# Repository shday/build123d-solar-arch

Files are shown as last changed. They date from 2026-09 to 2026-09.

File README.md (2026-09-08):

# build123d-solar-arch

Parametric 3D model of a **solar panel support arch**, generated in code with [build123d](https://build123d.readthedocs.io/) (Python CAD on OpenCASCADE). The script builds the complete structure — frames, feet, crossbars, braces, and lifting padeyes — from a handful of parameters, renders it in the ocp-vscode 3D viewer, and exports an STL mesh. It also builds a **crude sailboat stern context model** alongside the arch (front feet on the horizontal deck, back feet on the sloping transom) purely for visualization — the context hull is a separate part and never enters the STL export or the mass estimate.

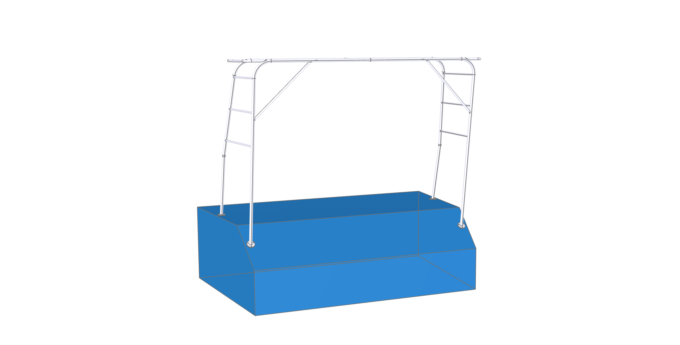
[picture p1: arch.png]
arch


## The model

A 3.1 m wide portal-style frame made of 40 mm round tube (2 mm wall), with:

- **Front and back frames** — filleted corners (R200) with horizontal top rails at 2 m. The **front legs** rise x-plumb (vertical when viewed from ahead) from the deck up to `leg_bend_height` = 0.8 m, then lean inboard toward the top corner; the aft rake is continuous along the whole leg, so the side view is unchanged. The plumb lower run lines the legs up with the boat's existing stern rails
- **Top-plane wings** — U-shaped Ø25 extensions capping both ends of the top bay in the top plane (z = 2 m): the front/back top rails continue ~0.25 m outboard (`wing_extend`) and are joined by a round bar with tight R75 corners, so the wings + arch top form one rounded rectangle ≈ 3.0 m × 0.8 m — extra mounting length for solar panels and clamp points (e.g. a Starlink antenna)
- **ArchFeet** — Ø100 × 8 mm base plates with a Ø30 centre hole and 3× Ø8.5 bolt holes (PCD 75)
- **Top support & center support** — Ø25 crossbars spanning front ↔ back at the top
- **Three side rails** per side — Ø25 panel-mounting rails running between the front and back legs at even heights: one at `side_rail_drop` below the top plane, one `side_rail_bottom_height` (1 m) above the deck, and one halfway between. Each rail is anchored at the same z on both legs, so every rail is level and parallel to the top support whatever rake/tilt the legs have
- **Diagonal brace** — Ø25 bracing in the plane of the back frame
- **Two padeyes** — Ø25 half-torus lifting lugs on the outside of the back top rail
- The half-model is mirrored about mid-span for a symmetric structure

A **crude stern-context hull** is shown beside the arch (translucent, not fused):
a flat deck at z=0 carries the front (flat) feet, while the back (tilted) feet
rest on a sloped transom/scoop surface. The scoop plane is *measured from the
arch's own back feet* (`back_foot_angle`, `drop`), and the hull is carved so
that plane becomes its aft top surface — the arch therefore always sits flush
on the hull. See the `boat_*` / `deck_width_*` parameters.

Current export: `arch.stl`, arch only (~22 MB, ~440k triangles — the STL mesh
density inflated after the plumb knee and wings were added, an OCCT meshing
artefact; geometry is unchanged in volume/fit checks); the context hull is never
included.

## Requirements

- Python 3.13 + conda environment `ocp` (build123d 0.11.1, cadquery-ocp-novtk, ocp-vscode, numpy, …)

Create the environment:

```bash
conda env create -f environment.yaml   # env name: ocp
```

## Running

```bash
cd /path/to/build123d-solar-arch   # run from the project root
conda activate ocp
python solar_arch.py
```

This builds the model, sends it to the 3D viewer (`show(arch2, boat)`), and writes `arch.stl` (`export_stl`) plus `arch.png` (`save_screenshot`, requires the viewer to be open).

> **Headless runs:** pass `--no-viewer` to skip `show()`/`save_screenshot()` while
> still building the geometry, running the fit checks, and exporting `arch.stl`:
> `python solar_arch.py --no-viewer`.

> **Run from the project directory.** `solar_arch.py` is opened relative to your
> current working directory, not the script's location. If you get
> `python: can't open file '.../solar_arch.py': No such file or directory`, you are
> in the wrong folder — `cd` into this repo first (check with `pwd`).

> **No conda on PATH?** Conda isn't initialized in your shell yet. Either run once
> `<conda-prefix>/bin/conda init zsh` (e.g. `/Users/stephenday/miniconda3/bin/conda init zsh`),
> or skip activation and call the env's interpreter directly:
> `<conda-prefix>/envs/ocp/bin/python solar_arch.py`.

## Viewing & screenshots

`show()` needs a running viewer:

- **VSCode** — install the *OpenCascade CAD Viewer* extension (`bernhard-42.ocp-cad-viewer`).

  **Recommended flow:** open `solar_arch.py` as the active tab in VSCode — the
  `from ocp_vscode import *` line auto-launches the viewer (`Ocp CAD Viewer >
  Advanced: Autostart`). Confirm the viewer is up: the VSCode status bar shows
  `OCP: <port>` and `~/.ocpvscode` lists that port under `services`. Then run the
  script from **that VSCode window's integrated terminal**:

  ```bash
  python solar_arch.py
  ```

  If the viewer doesn't auto-start, open it manually via the Command Palette
  (`Cmd+Shift+P`) → **"OCP CAD Viewer: Open viewer"**. If `show()` still reports
  `Port could not be cast to integer value as 'None'`, no viewer is registered —
  ensure the viewer panel is open before running.
- **Standalone (no VSCode)** — start the built-in browser viewer:

  ```bash
  python -m ocp_vscode          # serves http://127.0.0.1:3939/viewer
  ```

  Open that URL, then run `solar_arch.py` — the model appears in the browser.

> **Version pairing:** the `ocp-vscode` Python package and the *OCP CAD Viewer*
> VSCode extension are released in lockstep and must match (currently 4.0.1).
> If `show()` fails with `KeyError` (e.g. `'none'` or `0`) in `config.status()`,
> your Python package and extension versions are out of sync — upgrade the
> Python side with `pip install -U ocp-vscode==<extension version>`.

The script saves `arch.png` automatically at the end of each run (`save_screenshot`), so the preview stays in sync with the model. To capture a different view manually:

```python
from ocp_vscode import save_screenshot
save_screenshot("other.png")    # saved relative to the process working directory
```

Or use the camera/screenshot button in the viewer toolbar.

## Parameters

All dimensions are in **millimetres** (`M` = 1000, `MM` = 1). Edit the constants at the top of `solar_arch.py`:

| Parameter | Default | Description |
|---|---|---|
| `width` | 3.1 m | total span (x direction) |
| `back_width` | 2.9 m | span between the back feet |
| `back_inset` | 0.1 m | `(width − back_width) / 2`, leg inset from the outside |
| `height` | 2.0 m | top rail height |
| `depth` | 1.0 m | front-to-back depth of the frame |
| `drop` | 0.2 m | how far the back feet sit below the deck/scoop crease (transom drop) |
| `back_foot_angle` | 40° | tilt of the back foot plates — sets the transom/scoop slope the hull is built to |
| `front_offset` / `back_offset` | 0.5 / 0.3 m | aft rake of the front / back legs at the top |
| `leg_bend_height` | 0.8 m | height above the deck where the front legs start leaning inboard (they rise x-plumb below this, for stern-rail alignment) |
| `wing_extend` | 0.25 m | how far the top-plane wings extend outboard past the top rail ends |
| `wing_od` | 25 mm | wing tube outer diameter (ID 22 mm at `rail_wall_thickness`) |
| `wing_corner_radius` | 75 mm | tight radius of the wings' U corners (vs the arch's R200) |
| `tube_od` / `wall_thickness` | 40 / 2 mm | frame tube outer diameter and wall thickness (ID 36 mm) |
| `rail_wall_thickness` | 1.5 mm | wall of the Ø25 secondary members (cross members, side supports, wings) |
| `cross_member_od` | 25 mm | cross-member (top support, side rails, brace, center support) outer diameter (ID 22 mm at `rail_wall_thickness`) |
| `bend_radius` | 200 mm | corner fillet radius (`5 × tube_od`) |
| `top_support_offset` | 0.25 m | top crossbar position along the top rails |
| `side_rail_drop` | 0.2 m | how far below the top plane the top side rail sits (all rails are anchored at equal heights on both legs, so each is level by construction) |
| `side_rail_bottom_height` | 1.0 m | height of the lowest side rail above the deck (the middle rail sits halfway between this and the top rail) |
| `brace_offset` | 0.5 m | diagonal brace position along the back legs |
| `rise_rate` | 0 | experimental crown rise (`TangentArc`); `0` = flat top |
| `show_boat` | True | build & show the crude stern-context hull beside the arch |
| `boat_cx` | 1.55 m | boat centreline x (`width/2`); hull symmetric about it |
| `deck_width_aft` | 3.0 m | hull width at the aft end (`hull_aft_end`) |
| `deck_width_fwd` | 3.4 m | hull width at the forward cut |
| `hull_aft_end` | 1.3 m | hull aft extent below the scoop surface |
| `hull_len_aft` | 1.5 m | modeled hull length forward of the transom crease |
| `hull_bottom_z` | −1.0 m | flat-bottom depth |

## Project layout

```
solar_arch.py      parametric model (single script)
arch.stl           exported STL mesh
environment.yaml   conda environment (Python 3.13)
arch.png           rendered preview
LICENSE            Apache License 2.0
```

## Known issues

- **build123d 0.11.1 mirror bug:** the generic `mirror()` operation deep-copies the
  part internally, and on this geometry the copy corrupts trimmed-curve parameters
  (OCCT `Geom_TrimmedCurve::parameters out of range`). The script therefore mirrors
  via `arch2.part.mirror(plane)` (no copy) and `add()`s the result — keep that
  pattern for any new mirroring.
- `rise_rate` and the `TangentArc` branch are experimental; `back_foot_angle` and the
  `faces().sort_by(Axis.Z)[-4]` foot split index are empirical values.

## License

Apache License 2.0 — see [LICENSE](LICENSE).

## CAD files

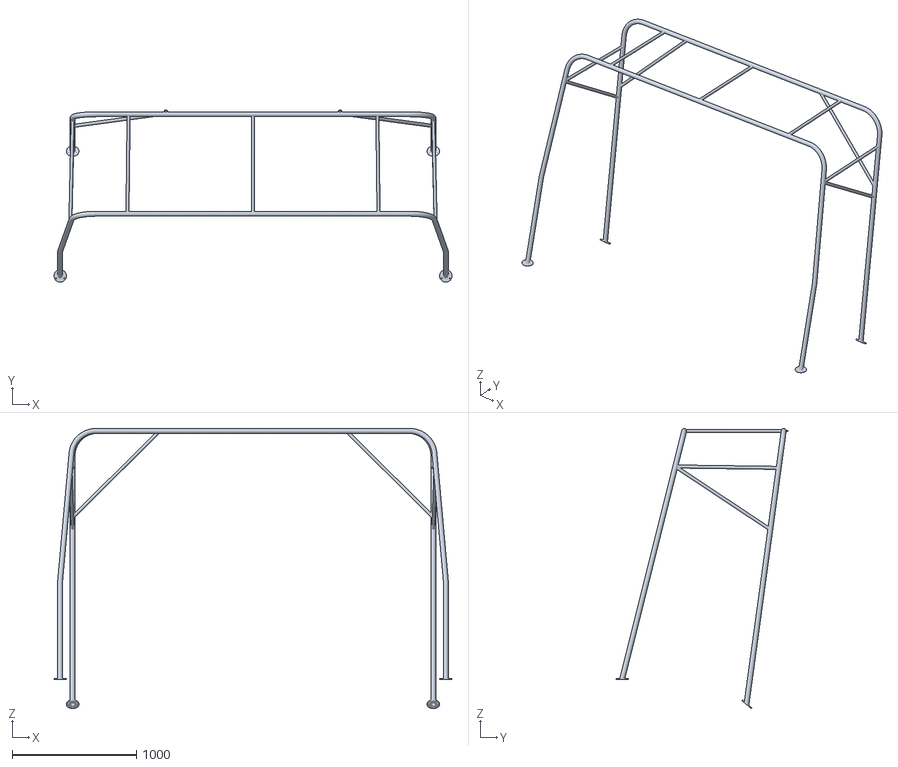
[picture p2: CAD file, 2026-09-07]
arch.stl
3200.0 x 1385.5 x 2252.1

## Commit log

2025-09-11 added stl export
    [arch.stl]
2025-09-12 make side supports parallel with top support
    [arch.stl]
2026-08-30 fix padeye phantom copies from add() in Locations
    add() inside a Locations context re-applies the location in this
    build123d dev build, duplicating the padeye at 2x the position.
    Construct the Padeye directly in the Locations block instead, remove
    debug prints and dead padeye experiment code, and re-enable the STL
    export with a fresh arch.stl.
    [arch.stl]
2026-08-31 Add 316 stainless steel mass estimation
    - part_mass()/volume_mass() helpers using the solid CAD volume
    - capture front/back foot volumes before fusion for a feet vs
    structure mass breakdown
    - print the mass report after the STL export
2026-08-31 Reduce tube wall thickness to 2 mm
    - wall_thickness 3 -> 2 mm (tube ID 34 -> 36 mm); update README
    description and parameters table
    - regenerate arch.stl for the thinner wall
    [arch.stl]
2026-08-31 Use 25 mm OD tube for cross-members
    [arch.stl]
2026-09-07 Add crude sailboat stern context model to the arch scene
    Build a visualization-only hull beside the solar arch so it can be seen mounted on a sailboat stern: the flat front feet rest on a horizontal deck (z=0) while the tilted back feet rest on a sloping t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
    The context hull is a separate BuildPart: it never enters arch.stl or the steel mass estimate. Hull dimensions (deck_width_fwd/aft, hull length/depth) are parameters; add --no-viewer for headless run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
2026-09-07 Narrow arch and deck widths to 3.1 m hull
    [arch.stl]
2026-09-07 Add plumb 0.8 m knee to front arch legs
    Front legs now rise x-plumb from the deck to leg_bend_height (0.8 m)
    and only then lean inboard toward the unchanged top corner, so they
    can line up with the boat's existing stern rails. The aft rake is
    continuous, keeping the side view identical; the visible top span
    is held at its exact current length/position via a corner-vertex
    compensation. Side rails re-anchored to the leg's upper straight run
    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
    [arch.stl]
2026-09-08 Refresh arch.png preview with plumb front-leg knees
2026-09-08 Add U-shaped top wings extending the panel bay outboard
    Each wing continues the front and back top rails ~0.25 m outboard
    (wing_extend) in the top plane and joins their ends with a round bar
    at R75 corners (wing_corner_radius), on 25 mm tube (wing_od), so both
    wings and the arch top form a ~3.0 m x 0.8 m rounded rectangle for
    larger solar arrays and Starlink/antenna mounting points. Wing legs
    fuse into the R200 corner fillets at the arch corners. The starboard
    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
2026-09-08 Refresh arch.png preview with top wings
2026-09-08 Use 1.5 mm rail_wall_thickness for cross members and wings
    New rail_wall_thickness parameter applies to all 25 mm secondary
    members (cross members, side supports, wings), while the 40 mm
    structural arch tubes keep wall_thickness = 2 mm.
2026-09-08 Anchor side rails by height and add three per side
    Replace the along-edge offset placement (and its side_support_adjustment
    fudge factor) with leg_point_at_height(): each rail end is placed at an
    absolute z on its leg, so rails are level and parallel to the top support
    by construction, whatever rake/tilt the legs have. Build three Ø25 rails
    per side - side_rail_drop below the top plane (z=1.8 m), 1 m above the
    deck (side_rail_bottom_height, z=1.0 m), and the midpoint between them
    (z=1.4 m). Drop the second sloped rail.
